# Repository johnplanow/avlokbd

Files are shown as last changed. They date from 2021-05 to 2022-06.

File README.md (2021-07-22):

# Avlo44 Keyboard

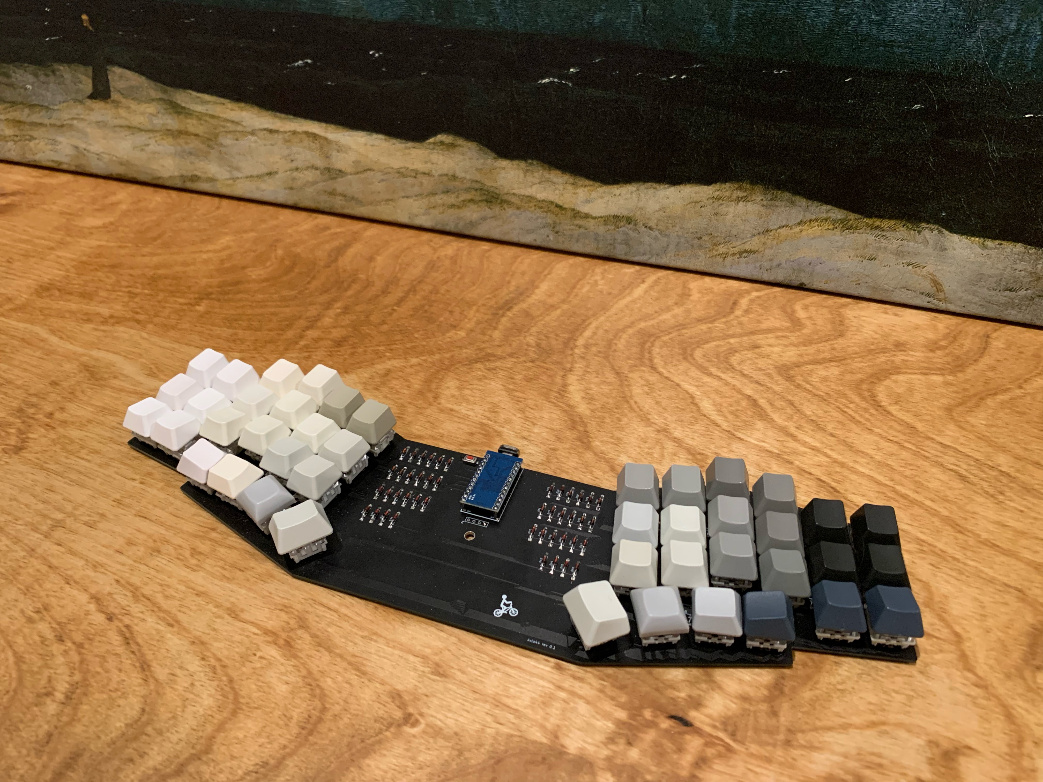
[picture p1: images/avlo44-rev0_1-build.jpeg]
Avlo44 Build

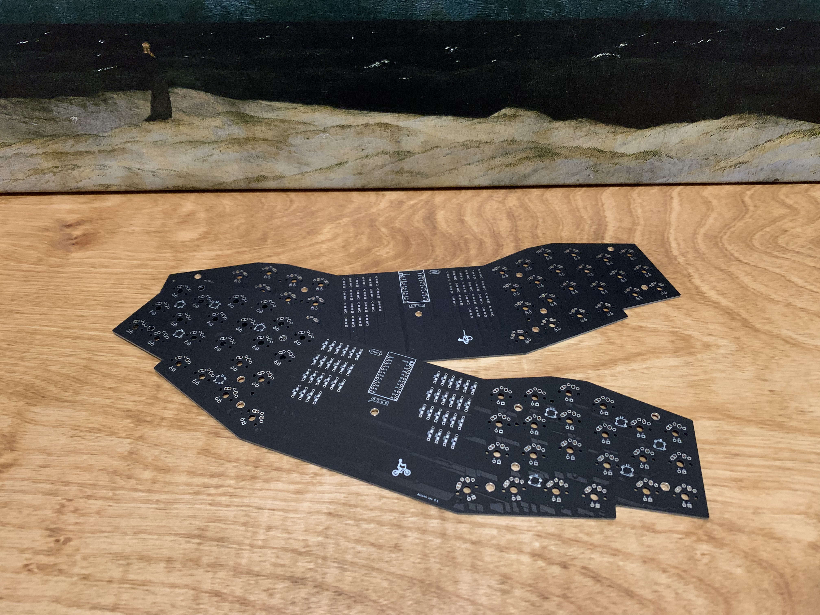
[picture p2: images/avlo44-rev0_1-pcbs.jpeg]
Avlo44 PCBs


Avlo44 is a 6x3+4 column-staggered, split, unibody keyboard. 

Inspired by the [Kyria](https://blog.splitkb.com/blog/introducing-the-kyria), 
[Reviung41](https://github.com/gtips/reviung) and [Lily58](https://github.com/kata0510/Lily58), it was designed with the following goals in mind:

* **Goal**: Easy to carry around the office with my laptop when I have meetings.
  * *Choice*: Unibody design. I like split keyboards, but they can be awkward to pick up and carry around.
  * *Choice*: Wireless. I intend to install a [nice!nano](https://nicekeyboards.com/nice-nano/) on the board eventually.
* **Goal**: Minimize keymap customization and learning curve for everyday office work and programming.<sup>1</sup>
  * *Corollary*: This means 3x6 with dedicated keys for all Mac modifiers. I don't find a worthwhile tradeoff in fewer keys.
  * *Choice*: 44 keys in a 6x3+4 layout.
* **Goal**: Experiment with an aggressive column-stagger, especially for the pinky. This seems intuitive to me, given my pinky is significantly shorter than other fingers.
  * *Choice*: The column-stagger is lifted directly from the [Kyria](https://blog.splitkb.com/blog/introducing-the-kyria). All credit to [Thomas Baart](https://thomasbaart.nl/) for its design.
* **Goal**: Ease of assembly
  * *Choice*: Through-hole diodes were used instead of surface-mount. Initial revisions still have surface-mount LEDs because I didn't care enough about backlighting to invest additional effort into them.
* **Goal**: Fun stuff!
  * *Choice*: I included an OLED, which has always been more fun than functional for me, because it's relatively easy. I will probably add a rotary encoder in a follow-up revision.

Future plans:
* 4x6 variant:
  * I have a PC used mostly for gaming. I'd like a dedicated number row for this<sup>1</sup> paired with the aggressive column-stagger.
* Breakaway sixth columns (for a 3x5 variant), as requested by someone when I first posted the Avlo44.
* Choc switch support, as requested by someone when I first posted the Avlo44.
* As mentioned above, I'd like to experiment with a rotary encoder.

## Footnotes

<sup>1</sup> In my experience, there is an inflection point as one reduces the number of keys, where there is a drastic increase in the complexity of keymap customizations (combos, layers, mod-taps, etc.) I think this inflection point depends on application: general office work versus programming versus gaming. In all cases, moving beyond it requires significantly more time/energy to adapt, tune, etc.

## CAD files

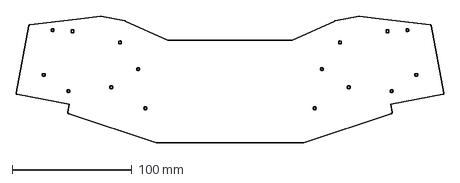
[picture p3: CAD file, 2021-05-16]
avlo68/case/bottom.dxf
356.6 x 105.4 mm

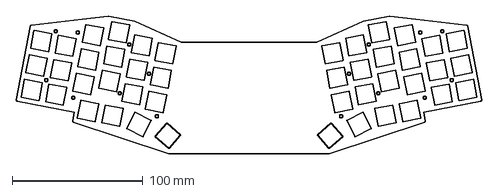
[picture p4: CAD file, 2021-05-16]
avlo68/case/plate_case.dxf
356.6 x 105.4 mm

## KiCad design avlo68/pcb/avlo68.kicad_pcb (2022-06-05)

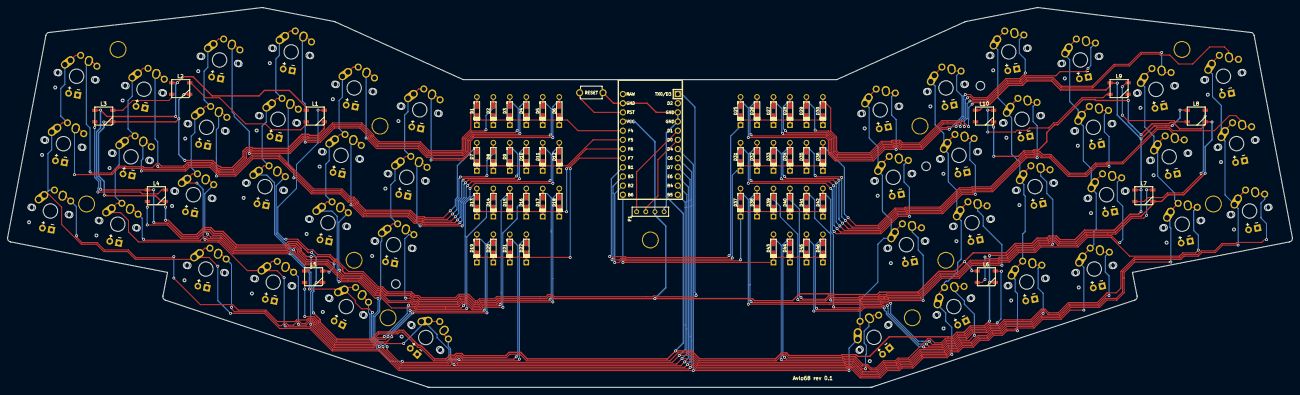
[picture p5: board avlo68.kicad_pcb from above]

Board: 2 copper layers, 356.5 x 105.4 mm, 112 parts (1 on the bottom side), 73 nets.

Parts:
D1, D2, D3, D4, D5, D6, D7, D8, D9, D10, D11, D12, D13, D14, D15, D16, D17, D18, D19, D20, D21, D22, D25, D26, D27, D28, D29, D30, D31, D32, D33, D34, D35, D36, D37, D38, D39, D40, D41, D42, D43, D44, D45, D46: 1N4148W; Diode-dual
L1, L2, L3, L4, L5, L6, L7, L8, L9, L10: WS2812B
P1: OLED; OLED_4Pin
RESET1: SW_PUSH; TACT_SWITCH_TVBP06
SW1, SW2, SW3, SW4, SW5, SW6, SW7, SW8, SW9, SW10, SW11, SW12, SW13, SW14, SW15, SW16, SW17, SW18, SW19, SW20, SW21, SW22, SW25, SW26, SW27, SW28, SW29, SW30, SW31, SW32, SW33, SW34, SW35, SW36, SW37, SW38, SW39, SW40, SW41, SW42, SW43, SW44, SW45, SW46: SW_PUSH; MX-Alps-Choc-1U
TH1, TH2, TH3, TH4, TH5, TH6, TH7, TH8, TH9, TH10, TH11: HOLE; HOLE_M2_TH
U1: ProMicro; ArduinoProMicro

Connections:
GND: L1.3, L2.3, L3.3, L4.3, L5.3, L6.3, L7.3, L8.3, L9.3, L10.3, P1.4, RESET1.2, U1.3, U1.4, U1.23
LED: L1.4, U1.1
unnamed: D1.2, SW1.2
unnamed: D2.2, SW2.2
unnamed: D3.2, SW3.2
unnamed: D4.2, SW4.2
unnamed: D5.2, SW5.2
unnamed: D6.2, SW6.2
unnamed: D7.2, SW7.2
unnamed: D8.2, SW8.2
unnamed: D9.2, SW9.2
unnamed: D10.2, SW10.2
unnamed: D11.2, SW11.2
unnamed: D12.2, SW12.2
unnamed: D13.2, SW13.2
unnamed: D14.2, SW14.2
unnamed: D15.2, SW15.2
unnamed: D16.2, SW16.2
unnamed: D17.2, SW17.2
unnamed: D18.2, SW18.2
unnamed: D19.2, SW19.2
unnamed: D20.2, SW20.2
unnamed: D21.2, SW21.2
unnamed: D22.2, SW22.2
unnamed: D25.2, SW25.2
unnamed: D26.2, SW26.2
unnamed: D27.2, SW27.2
unnamed: D28.2, SW28.2
unnamed: D29.2, SW29.2
unnamed: D30.2, SW30.2
unnamed: D31.2, SW31.2
unnamed: D32.2, SW32.2
unnamed: D33.2, SW33.2
unnamed: D34.2, SW34.2
unnamed: D35.2, SW35.2
unnamed: D36.2, SW36.2
unnamed: D37.2, SW37.2
unnamed: D38.2, SW38.2
unnamed: D39.2, SW39.2
unnamed: D40.2, SW40.2
unnamed: D41.2, SW41.2
unnamed: D42.2, SW42.2
unnamed: D43.2, SW43.2
unnamed: D44.2, SW44.2
unnamed: D45.2, SW45.2
unnamed: D46.2, SW46.2
unnamed: L1.2, L2.4
unnamed: L2.2, L3.4
unnamed: L3.2, L4.4
unnamed: L4.2, L5.4
unnamed: L5.2, L6.4
unnamed: L6.2, L7.4
unnamed: L7.2, L8.4
unnamed: L8.2, L9.4
unnamed: L9.2, L10.4
SCL: P1.2, U1.6
SDA: P1.1, U1.5
VCC: L1.1, L2.1, L3.1, L4.1, L5.1, L6.1, L7.1, L8.1, L9.1, L10.1, P1.3, U1.21
col0: SW1.1, SW7.1, SW13.1, SW19.1, SW25.1, SW31.1, SW37.1, SW43.1, U1.7
col1: SW2.1, SW8.1, SW14.1, SW20.1, SW26.1, SW32.1, SW38.1, SW44.1, U1.8
col2: SW3.1, SW9.1, SW15.1, SW21.1, SW27.1, SW33.1, SW39.1, SW45.1, U1.9
col3: SW4.1, SW10.1, SW16.1, SW22.1, SW28.1, SW34.1, SW40.1, SW46.1, U1.10
col4: SW5.1, SW11.1, SW17.1, SW29.1, SW35.1, SW41.1, U1.11
col5: SW6.1, SW12.1, SW18.1, SW30.1, SW36.1, SW42.1, U1.12
reset: RESET1.1, U1.22
row0: D1.1, D2.1, D3.1, D4.1, D5.1, D6.1, U1.20
row1: D7.1, D8.1, D9.1, D10.1, D11.1, D12.1, U1.19
row2: D13.1, D14.1, D15.1, D16.1, D17.1, D18.1, U1.18
row3: D19.1, D20.1, D21.1, D22.1, U1.17
row4: D25.1, D26.1, D27.1, D28.1, D29.1, D30.1, U1.16
row5: D31.1, D32.1, D33.1, D34.1, D35.1, D36.1, U1.15
row6: D37.1, D38.1, D39.1, D40.1, D41.1, D42.1, U1.14
row7: D43.1, D44.1, D45.1, D46.1, U1.13

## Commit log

2021-05-16 Add PCB for Avlo44 with initial routing for left half
    [avlo44.kicad_pcb, avlo44.sch, plate_case.dxf]
2021-05-16 Initial routing complete for Avlo44
    [avlo44.kicad_pcb, avlo44.sch, plate_case.dxf]
2021-05-16 Add gitignore and bottom plate
    [bottom.dxf]
2021-05-16 Add board outline for Avlo44
    [avlo44.kicad_pcb]
2021-05-18 Update mounting holes, add artwork and add production files
    [avlo44-B_Cu.gbl, avlo44-B_Mask.gbs, avlo44-B_SilkS.gbo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]
2021-06-02 Fix missing trace and add switch footprint for Kailh socket
    [avlo44.kicad_pcb, avlo44.sch]
2022-06-05 Duplicate avlo44 project for avlo68. Update matrix schematic.
    [avlo68.kicad_pcb, avlo68.sch, bottom.dxf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]
2022-06-05 Add Black Pill footprint and schematic. Drop Black Pill onto avlo68 schematic.
    [avlo68.sch]
2022-06-12 Add rotary encoders and OLED to schematic
    [avlo68.sch]
